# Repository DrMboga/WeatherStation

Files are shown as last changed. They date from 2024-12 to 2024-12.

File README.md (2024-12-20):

# Home Weather Station

An ESP32 based home weather station which measures the current temperature, fetches hourly weather forecast and shows everything at the LCD display.

---

## Project Overview

The **Home Weather Station** uses an ESP32 microcontroller to collect and display data. A 16x2 LCD shows:

- Temperature and humidity in three rooms of my apartment.
- Outdoor temperature and humidity.
- Hourly weather forecasts (e.g., "Sunny," "Rainy," or "Cloudy").

The system integrates hardware, a custom backend, and third-party APIs to ensure seamless functionality.

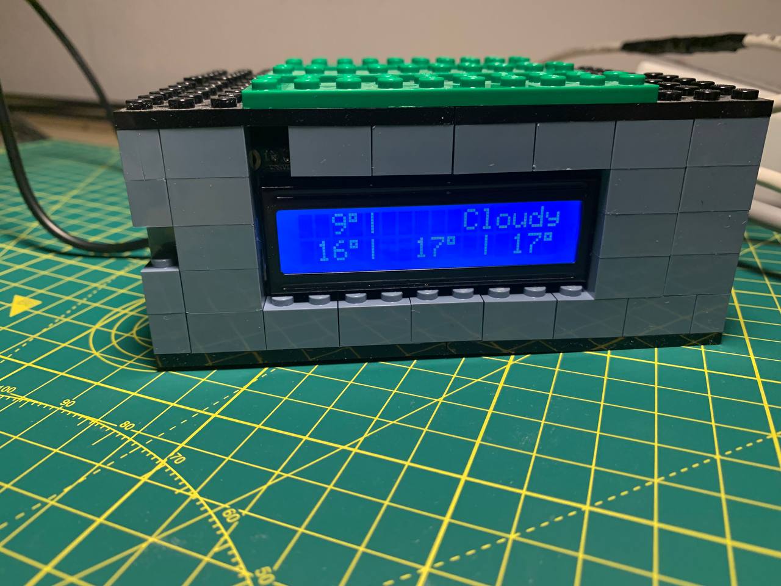
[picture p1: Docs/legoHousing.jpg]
Housing picture


---

## Hardware Components

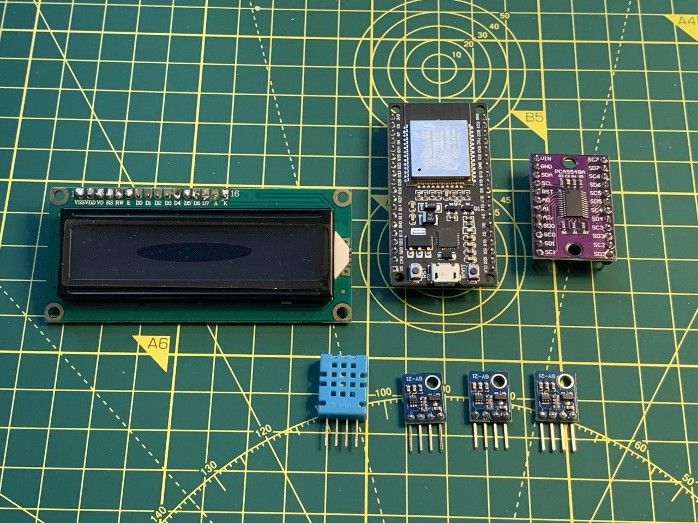
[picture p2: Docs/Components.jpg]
Components


- [ESP32 board](https://www.az-delivery.de/en/products/esp-32-dev-kit-c-v4)
- [Multiplexer](https://www.az-delivery.de/en/products/tca9548a-i2c-iic-multiplexer)
- [GY-21 sensor](https://www.az-delivery.de/en/products/gy-21-temperatur-sensor-modul)
- [DHT-11 sensor](https://www.az-delivery.de/en/products/5-x-dht11-temperatursensor)
- [LCD](https://www.az-delivery.de/en/products/16x2-lcd-blaues-display)

### Sensors and Connectivity

The system collects environmental data using four sensors:

1. **DHT-11 Sensor:**

   - This sensor is connected directly to the ESP32 via a GPIO pin and placed outside the apartment window to measure outdoor temperature and humidity.

2. **Three GY-21 Sensors:**
   - These sensors monitor indoor conditions in three rooms.
   - All GY-21 sensors share the same I2C address, which typically causes a conflict when connecting them to the same bus.

### I2C Multiplexer TCA9548A

To resolve the address conflict of the GY-21 sensors, the system uses the TCA9548A I2C multiplexer. This device allows the ESP32 to switch between its ports, enabling communication with each sensor sequentially. Here's how it works:

- The multiplexer creates 3 independent I2C channels.
- The ESP32 activates one channel at a time, isolating the selected sensor.
- Data from all three GY-21 sensors can be read sequentially without interference.

The TCA9548A is crucial for enabling multiple identical devices to coexist on a single I2C bus, making it an essential component in this project.

### Display

The **16x2 LCD screen** serves as the user interface, showing real-time data such as:

- Indoor and outdoor conditions.
- Current weather forecast.  
  The clear and simple display ensures the station is easy to read at a glance.

### Enclosure

To house the components, I built a custom enclosure out of Lego bricks. This design offers:

- **Protection:** Safeguards the ESP32, multiplexer, and display from damage.
- **Flexibility:** Allows easy access for upgrades or repairs.
- **Aesthetic Appeal:** Adds a fun and personalized touch to the project.

The sensors are connected to the ESP32 using old patch cables, which provide a reliable and flexible way to extend their range.

### Connection scheme

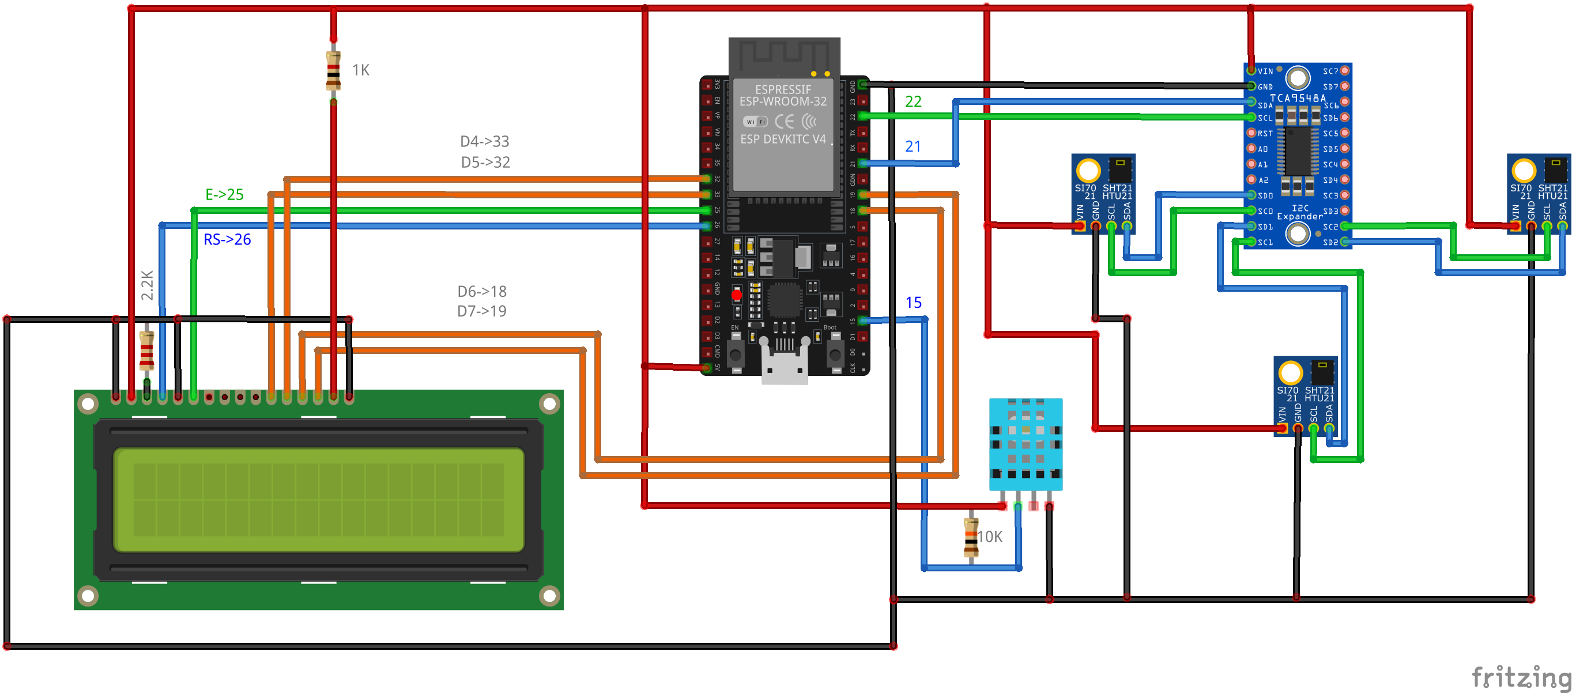
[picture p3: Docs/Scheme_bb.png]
Scheme


---

## Software Architecture

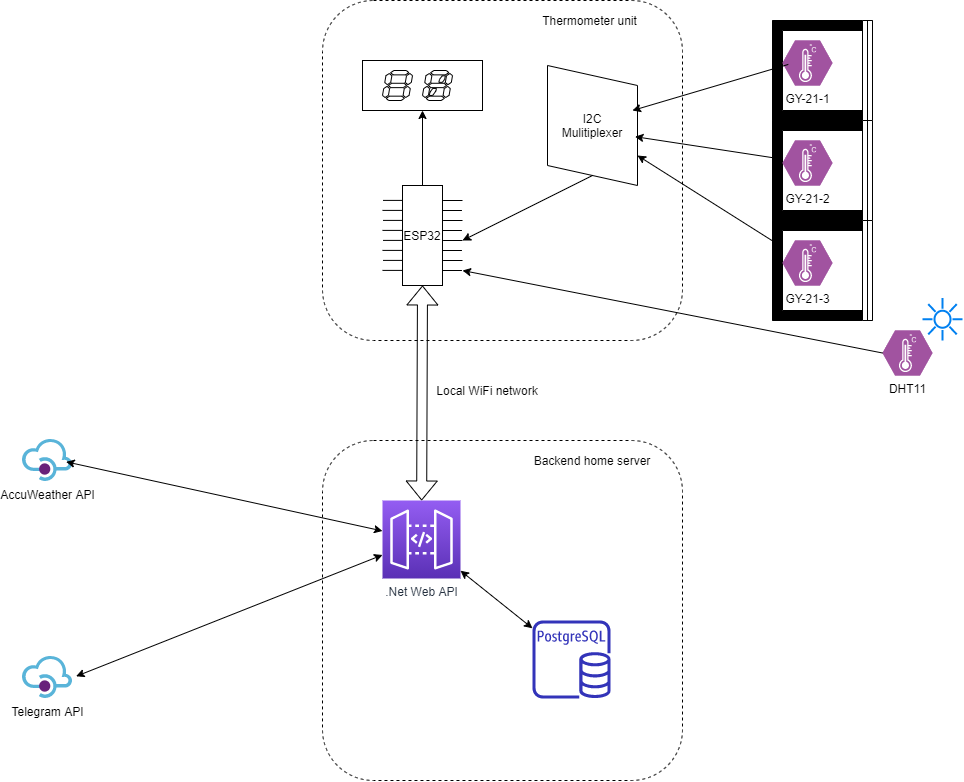
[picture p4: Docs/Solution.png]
Architecture


### ESP32 Firmware

The ESP32 is the brain of the operation. It communicates with the backend over WiFi and performs the following tasks:

1. **Data Collection:** Reads sensor data at regular intervals.
2. **Data Transmission:** Sends the collected data to the backend using a **POST** request every 6 hours.
3. **Forecast Retrieval:** Requests hourly weather forecasts from the backend via a **GET** request and displays them on the LCD.

The firmware is designed to be efficient and robust, ensuring smooth operation even over extended periods.

### Backend System

The backend is a **.NET Web API** application hosted on a local Linux server. It manages three main tasks:

1. **Storing Sensor Data:**

   - A POST endpoint receives data from the ESP32 and stores it in a PostgreSQL database. This creates a historical log of temperature and humidity readings for future analysis.

2. **Providing Hourly Forecasts:**

   - A GET endpoint retrieves hourly forecasts from the **AccuWeather API** and returns them to the ESP32.
   - By leveraging AccuWeather's free tier, the system stays within the 50 requests per day limit while maintaining accuracy.

3. **Sending Daily Summaries to Telegram:**
   - A scheduled job runs every morning to:
     - Fetch the latest sensor readings from the database.
     - Retrieve a 12-hour weather forecast from AccuWeather.
     - Compile this data into a summary message.
     - Send the message via the **Telegram Bot API** to a subscribed channel.

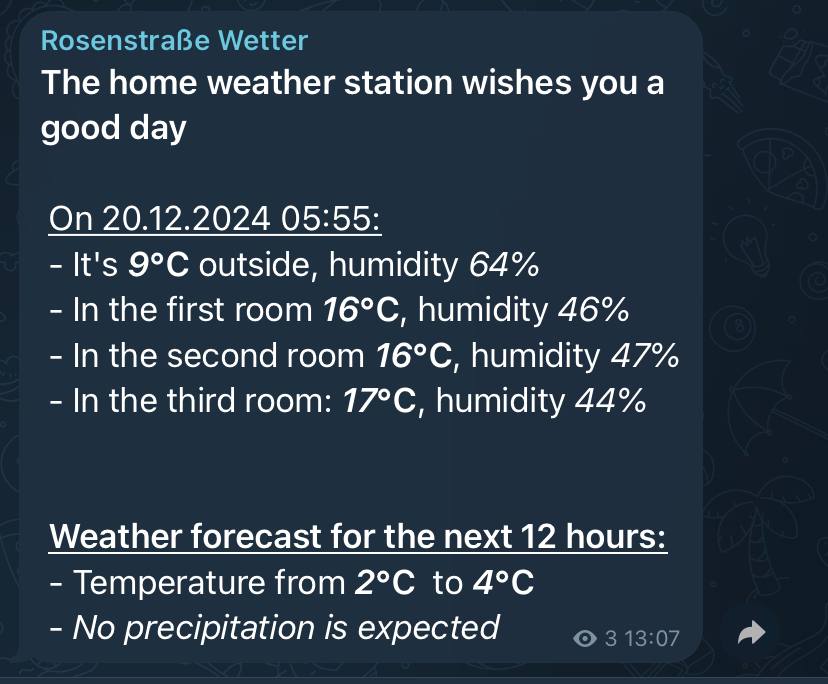
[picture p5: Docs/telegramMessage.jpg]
Telegram message


This integration ensures that I get an automated weather summary on my phone every morning.

---

## Code and deployment

- [Here is the Platform IO project with sketch for ESP32](./Esp32/)
- [Here is the backend .net project](./backend/)
- [Here is a small "HowTo" for creating a Telegram bot and using it via API](./backend/telegram.md)
- [Here is some instructions how to set up a home server using Linux](./backend/deploy.md) (In my case this is a Raspberry Pi 4 board computer)

---

## Daily Benefits

The **Home Weather Station** has become an invaluable tool in my daily life:

- **Real-time Monitoring:** The LCD provides up-to-date information about the conditions inside and outside my apartment.
- **Hourly Forecasts:** Help me plan activities based on expected weather changes.
- **Morning Summaries:** A Telegram notification delivers a convenient summary of the day’s conditions and forecast.

These features make the station both practical and easy to use.

## Final Thoughts

The **Home Weather Station** has been a rewarding journey into the world of IoT. Combining hardware and software taught me new skills and gave me a practical tool for my everyday life. Whether you’re an IoT enthusiast or looking for a new DIY challenge, I hope this inspires you to build something similar.

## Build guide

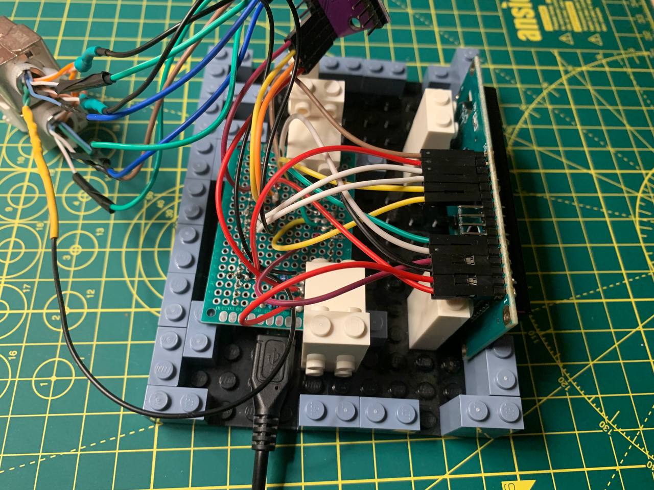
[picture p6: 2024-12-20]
Docs/legoAssembly.jpg

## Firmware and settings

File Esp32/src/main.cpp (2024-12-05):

#include "dht.h"
#include "lcd.h"
#include "gy21.h"
#include "secrets.h"
#include "ntp.h"
#include "backendClient.h"

#include <WiFi.h>

/*
Don't forget to add "secrets.h" to the project with this content:
#define WIFI_SSID "your-SSID"
#define WIFI_PASSWORD "your-PASSWORD"
*/

float dht11Temperature = -99.0;
float dht11Humidity = -99.0;
String forecastWord = "  Offline  ";

#define ITERATIONS_FOR_SCREEN_CHANGE (7)
bool isTemperatureShowing = true;
int currentIteration = 0;

bool isOffline = true;

// Hourly forecast schedule
#define MINUTE_TO_GET_FORECAST 55 // Gets forecast every hour at 55 minutes
int lastForecastHor = -1;

// Sending sensor readings schedule
#define MINUTE_TO_SEND_READINGS 55 // Sends readings to backend at 5:55, 11:55, 17:55, 23:55
uint8_t sendReadingsHours[] = {5, 11, 17, 23};
int lastSentReadingsHour = -1;


void connectToWiFi() {
  // Connect to Wi-Fi
  Serial.print("Connecting to ");
  Serial.println(WIFI_SSID);
  WiFi.begin(WIFI_SSID, WIFI_PASSWORD);
  
  for (size_t i = 0; i < 10; i++)
  {
    delay(500);
    Serial.print(".");
    if (WiFi.status() == WL_CONNECTED) {
      isOffline = false;
      break;
    }
  }
  Serial.println("");
  if (isOffline) {
    Serial.println("WiFi not connected. Going to offline mode.");
  }
  else {
    Serial.println("WiFi connected.");
  }
}

void setup() { 
  Serial.begin(115200);

  lcdSetup();

  if (!gy21Setup()) {
    Serial.println("Unable to setup GY-21 sensors or multiplexer.");
  }

  connectToWiFi();

  if(!isOffline) {
    configTime();
  }
}

void loop() {
  float currentDht11Temperature;
  float currentDht11Humidity;
  float gy211Temperature;
  float gy211Humidity;
  float gy212Temperature;
  float gy212Humidity;
  float gy213Temperature;
  float gy213Humidity;

  readDht11Data(currentDht11Temperature, currentDht11Humidity);
  // Sometimes dht11 reads data with error. In casee of error, it returns -99.
  // In case of error, showing previous vaules
  if (currentDht11Temperature > -90) {
    dht11Temperature = currentDht11Temperature;
  }
  if (currentDht11Humidity > -90) {
    dht11Humidity = currentDht11Humidity;
  }

  readGy21Data(0, gy211Temperature, gy211Humidity);
  readGy21Data(1, gy212Temperature, gy212Humidity);
  readGy21Data(2, gy213Temperature, gy213Humidity);

  // Show result
  currentIteration++;
  if (ITERATIONS_FOR_SCREEN_CHANGE == currentIteration) {
    currentIteration = 0;
    isTemperatureShowing = !isTemperatureShowing;
    lcdClear();
  }


  if (isTemperatureShowing) {
    lcdShowTemeperature(
      dht11Temperature,
      gy211Temperature,
      gy212Temperature,
      gy213Temperature
    );
  }
  else {
    lcdShowHumidity(
      dht11Humidity,
      gy211Humidity,
      gy212Humidity,
      gy213Humidity
    );
  }

  struct tm timeInfo;
  if (!isOffline && now(&timeInfo)) {
    if (lastForecastHor < 0 || (MINUTE_TO_GET_FORECAST == timeInfo.tm_min && lastForecastHor != timeInfo.tm_hour)) {
      Serial.print(timeInfo.tm_hour);
      Serial.print(":");
      Serial.print(timeInfo.tm_min);
      Serial.println(" Getting forecast");
      forecastWord = getForecastWord();
      lastForecastHor = timeInfo.tm_hour;
    }

    bool sendReadingsThisHour = false;
    for (size_t i = 0; i < 4; i++)
    {
        if (sendReadingsHours[i] == timeInfo.tm_hour) {
          sendReadingsThisHour = true;
          break;
        }
    }
    if((lastSentReadingsHour < 0 && dht11Temperature > -90) ||
    (MINUTE_TO_SEND_READINGS == timeInfo.tm_min && sendReadingsThisHour && lastSentReadingsHour != timeInfo.tm_hour)) {
      time_t epoch;
      if(nowEpoch(&epoch)) {
        sendReadingsToBackend(
          epoch,
          dht11Temperature,
          dht11Humidity,
          gy211Temperature,
          gy211Humidity,
          gy212Temperature,
          gy212Humidity,
          gy213Temperature,
          gy213Humidity
        );
        lastSentReadingsHour = timeInfo.tm_hour;
      }
    }
  }

  showForecastWord(forecastWord);
  
  Serial.print("DHT11 temperature: ");
  Serial.print((int)dht11Temperature);
  Serial.print("°, ");
  Serial.print((int)dht11Humidity);
  Serial.print("% | GY-21 No 1: ");
  Serial.print((int)gy211Temperature);
  Serial.print("°, ");
  Serial.print((int)gy211Humidity);
  Serial.print("% | GY-21 No 2: ");
  Serial.print((int)gy212Temperature);
  Serial.print("°, ");
  Serial.print((int)gy212Humidity);
  Serial.print("% | GY-21 No 3: ");
  Serial.print((int)gy213Temperature);
  Serial.print("°, ");
  Serial.print((int)gy213Humidity);
  Serial.println("%");

  delay(1500); // DHT11 sampling rate is 1HZ.
}

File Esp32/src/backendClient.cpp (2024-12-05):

#include "backendClient.h"

#include <WiFi.h>
#include <HTTPClient.h>
#include <Arduino_JSON.h>

const char* hourlyForecastUrl = "http://192.168.0.65:8830/getweatherforecastnexthour";
const char* sendReadingsUrl = "http://192.168.0.65:8830/savesensorreadings";

String getWordByIcon(int icon);

String getForecastWord() {
    String response = "Undefined";

    HTTPClient http;
    http.begin(hourlyForecastUrl);

    int httpResponseCode = http.GET();

    if (httpResponseCode == 200) {
        Serial.print("HTTP Response code: ");
        Serial.println(httpResponseCode);
        String payload = http.getString();
        
        JSONVar forecast = JSON.parse(payload);
        if (JSON.typeof(forecast) == "undefined") {
            Serial.println("Parsing input failed!");
            response = "No JSON";
        }
        else {
            /*
            "weatherIcon" = 12
            "iconPhrase" = "Showers"            
            */
           int icon = forecast["weatherIcon"];
           String phrase = forecast["iconPhrase"];
           Serial.print(icon);
           Serial.print(": ");
           Serial.println(phrase);
           response = getWordByIcon(icon);
        }
      }
      else if (httpResponseCode == 503) {
        Serial.println("AccuWeather limit achieved");
        response = "Limit exc.";
      }  
      else {
        Serial.print("Error code: ");
        Serial.println(httpResponseCode);
        response = "HTTP Err";
      }

    // Free resources
    http.end();
    return response;
}

bool sendReadingsToBackend(
    time_t epoch,
    float outTemp,
    float outHum,
    float room1Temp,
    float room1Hum,
    float room2Temp,
    float room2Hum,
    float room3Temp,
    float room3Hum
) {
    Serial.println("Send readings");
    HTTPClient http;
    http.begin(sendReadingsUrl);

    http.addHeader("Content-Type", "application/json");
    String httpRequestData = "{\"measurementTimeStamp\": ";
    httpRequestData += String(epoch) + ",\"outside\": {\"temperature\":";
    httpRequestData += String(outTemp) + ",\"humidity\": ";
    httpRequestData += String(outHum) + "}, \"room1\": { \"temperature\": ";
    httpRequestData += String(room1Temp) + ", \"humidity\": ";
    httpRequestData += String(room1Hum) + " }, \"room2\": { \"temperature\": ";
    httpRequestData += String(room2Temp) + ", \"humidity\": ";
    httpRequestData += String(room2Hum) + " }, \"room3\": { \"temperature\": ";
    httpRequestData += String(room3Temp) + ", \"humidity\": ";
    httpRequestData += String(room3Hum) + " }}";

    Serial.println(httpRequestData);

    int httpResponseCode = http.POST(httpRequestData);

    Serial.print("Response code: ");
    Serial.println(httpResponseCode);

    bool result = httpResponseCode > 0;

    // Free resources
    http.end();
    return result;
}


String getWordByIcon(int icon) {
    // Codes are taken from here https://developer.accuweather.com/weather-icons
    switch (icon)
    {
    case 1:
    case 2:
    case 3:
    case 4:
    case 5:
        return "Sunny";
    case 6:
    case 7:
    case 36:
    case 38:
        return "Cloudy";
    case 8:
        return "Overcast";
    case 11:
    case 37:
        return "Fog";
    case 12:
    case 13:
    case 14:
    case 39:
    case 40:
        return "Showers";
    case 15:
    case 16:
    case 17:
    case 41:
    case 42:
        return "T-Storms";
    case 18:
        return "Rain";
    case 19:
    case 20:
    case 21:
    case 43:
        return "Flurries";
    case 22:
    case 23:
    case 44:
        return "Snow";
    case 24:
        return "Ice";
    case 25:
    case 26:
    case 29:
        return "Rain + Snow";
    case 30:
        return "Hot";
    case 31:
        return "Cold";
    case 32:
        return "Windy";
    case 33:
    case 34:
        return "Clear";
    default:
        return "No info";
    }
}

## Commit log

2024-11-28 feat: initial arduino project
2024-11-30 feat: multiplexer plus LCD formatting
    [Scheme.fzz]
2024-11-30 feat: esp32 code refactoring
2024-12-01 chore: esp32 code refactoring
2024-12-01 chore: error show on lcd
    [main.cpp]
2024-12-01 feat: ESP32 WiFi connection added
2024-12-04 chore: esp32 code restructure and dht11 workaround
    [main.cpp]
2024-12-04 feat: esp32 time reading
2024-12-04 feat: esp32 hourly forecast
2024-12-04 feat: esp32 send readings to backend request
2024-12-05 chore: esp32 showing accu weather limit error
    [backendClient.cpp]
2024-12-05 chore: fritzing scheme fixed
    [Scheme.fzz]
2024-12-10 chore: links to materials
